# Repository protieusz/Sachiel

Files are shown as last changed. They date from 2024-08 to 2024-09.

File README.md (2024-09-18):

# Sachiel
Sachiel, inspired by Grumpy, 34 keys custom keyboard with 25mm trackball

# Description
Sachiel is a 34 keys custom keyboard with an integrated 25mm trackball.
Even though Sachiel is inspired by Grumpy but the KLE layout is done from scratch with added missing keys. Nothing from the Grumpy's design was taken for modding i.e the pcb files or the stl. 
Sachiel name was derived from one of the angels of an anime.

The missing keys of Q, P, B and N were added to make it a standard 30 alpha keys. The win key and the enter key were add to row 3 and 10 of the layout.
The 2 keys, backspace and space were shrink to 1U.

The keeb is power by RP2040 Core-A mcu which you can get from AE. The rest of the components are purchased from LCSC.

The components are pcba by me using a hot plate and some hand soldering for the mcu, ESD, fuse, USB C and the switches. During designing, due to spacing issue for the ESD and the fuse, I got them to appear to the top side of pcb.

PMW3360 sensor is used for the trackball as per usual.

As for the case design, I have tried printing in both PLA and matte resin. The PLA has a good switch friction fit and working integrated trackball holder but the resin had loose switch holes and super super tight fitting M2 inserts. So print resin at your own risk I didn't use resin for this build.

As for the trackball ball, you can refer to my previous different designs for reference. Overall POM ball works the best for me. Other balls are hit and miss. Build this keeb on your own risk.

QMK code is the same modified from aki27's bally code. I don't how the code works and I just integrated my matrix and some trial and errors and it works now.

# Full Production




41BBA1AD-F132-4E0E-9B04-4C7E31181316














# Renders

Screenshot 2024-07-20 at 11 03 13 PM
Screenshot 2024-07-20 at 11 03 25 PM
Screenshot 2024-07-20 at 9 27 32 PM
Screenshot 2024-07-20 at 9 27 11 PM
Screenshot 2024-07-20 at 7 22 08 PM
Screenshot 2024-07-20 at 7 20 41 PM
Screenshot 2024-07-20 at 7 20 30 PM

# License

</a></p>

You are free to:

Share — copy and redistribute the material in any medium or format

Adapt — remix, transform, and build upon the material

The licensor cannot revoke these freedoms as long as you follow the license terms.
Under the following terms:

Attribution — You must give appropriate credit, provide a link to the license, and indicate if changes were made. You may do so in any reasonable manner, but not in any way that suggests the licensor endorses you or your use.

NonCommercial — You may not use the material for commercial purposes.

ShareAlike — If you remix, transform, or build upon the material, you must distribute your contributions under the same license as the original.

No additional restrictions — You may not apply legal terms or technological measures that legally restrict others from doing anything the license permits.

Sachiel by ProtieusKeebs is licensed under [CC BY-NC-SA 4.0](https://creativecommons.org/licenses/by-nc-sa/4.0/?ref=chooser-v1)

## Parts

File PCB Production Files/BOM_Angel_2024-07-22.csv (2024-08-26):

ID | Name | Designator | Footprint | Quantity | Manufacturer Part | Manufacturer | Supplier | Supplier Part | Price | link
1 | SM4007PL | D000,D001,D002,D003,D004,D005,D006,D007,D008,D009,D100,D101,D102,D103,D104,D105,D106,D107,D108,D109,D200,D201,D202,D203,D204,D205,D206,D207,D208,D209,D302,D304,D305,D307 | SOD-123F_L2.8-W1.8-LS3.7-RD | 34 | SM4007PL | MDD | LCSC | C64898 | 0.007 | https://item.szlcsc.com/60254.html
2 | 4.7uF | C17,C19,C20 | C0402 | 3 | CL05A475MP5NRNC | SAMSUNG(三星) | LCSC | C23733 | 0.005 | https://lcsc.com/eda_search?q=C23733&%26type=1&ref=editor
3 | 100nF | C18 | C0402 | 1 | CL05B104KB54PNC | SAMSUNG(三星) | LCSC | C307331 | 0.005 | https://lcsc.com/eda_search?q=C307331&%26type=1&ref=editor
4 | 5.1kΩ | R1,R2 | R0402 | 2 | 0402WGF5101TCE | UNI-ROYAL(厚声) | LCSC | C25905 | 0.001 | https://item.szlcsc.com/323315.html
5 | 10kΩ | R10,R12,R13 | R0402 | 3 | 0402WGF1002TCE | UNI-ROYAL(厚声) | LCSC | C25744 | 0.001 | https://lcsc.com/eda_search?q=C25744&%26type=1&ref=editor
6 | 39Ω | R11 | R0402 | 1 | 0402WGJ0390TCE | UNI-ROYAL(厚声) | LCSC | C25164 |  | https://lcsc.com/eda_search?q=C25164&%26type=1&ref=editor
7 | 15kΩ | R14 | R0402 | 1 | 0402WGF1502TCE | UNI-ROYAL(厚声) | LCSC | C25756 | 0.001 | https://lcsc.com/eda_search?q=C25756&%26type=1&ref=editor
8 | RP2040-Core-A | U1 | RP2040-CORE-A | 1
9 | AP2127K-ADJTRG1 | U10 | SOT-23-5_L3.0-W1.7-P0.95-LS2.8-BR | 1 | AP2127K-ADJTRG1 | DIODES(美台) | LCSC | C96343 | 0.072 | https://lcsc.com/eda_search?q=C96343&%26type=1&ref=editor
10 | PMW3360DM-T2QU | U11 | PMW3360DM-T2QU.PACK | 1 | PMW3360DM-T2QU |  |  |  |  | http://www.pixart.com/upload/PMS0058-PMW3360DM-T2QU-NNDS-R1.30-06042016_20160902201411.pdf
11 | TYPE-C-31-M-12 | USBC1 | USB-C_SMD-TYPE-C-31-M-12 | 1 | TYPE-C-31-M-12 | 韩国韩荣 | LCSC | C165948 | 0.157 | https://so.szlcsc.com/global.html?c=&k=C165948
12 | Switch | K000,K001,K002,K003,K004,K005,K006,K007,K008,K009,K100,K101,K102,K103,K104,K105,K106,K107,K108,K109,K200,K201,K202,K203,K204,K205,K206,K207,K208,K209,K302,K304,K305,K307 | CHERRY_MX_100_MILLMAX | 34
13 | PRTR5V0U2X,215 | D11 | SOT-143_L2.9-W1.3-P1.92-LS2.3-BR | 1 | PRTR5V0U2X,215 | Nexperia(安世) | LCSC | C12333 | 0.089 | https://item.szlcsc.com/280548.html
14 | BSMD0805-020-15V | F1 | F0805 | 1 | BSMD0805-020-15V | BHFUSE(佰宏) | LCSC | C883103 | 0.043 | https://item.szlcsc.com/343298.html

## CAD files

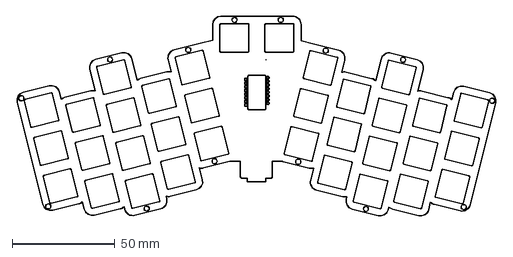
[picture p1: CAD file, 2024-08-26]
Angel Final PCB.dxf
233.6 x 97.5 mm

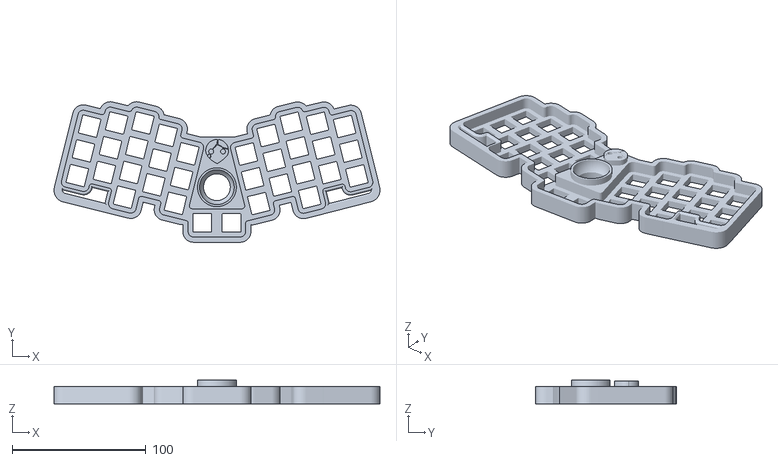
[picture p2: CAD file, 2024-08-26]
Sachiel STLs/SachielTop.stl
243.7 x 105.1 x 17.8

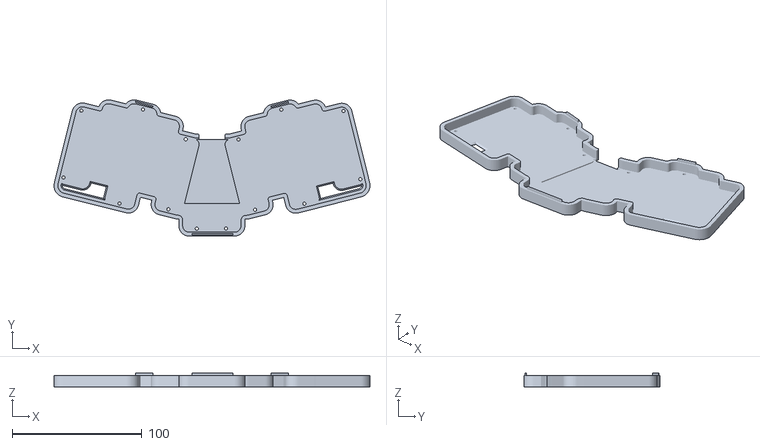
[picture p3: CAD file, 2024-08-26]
Sachiel STLs/Sachiel Bottom.stl
243.7 x 105.1 x 10.6

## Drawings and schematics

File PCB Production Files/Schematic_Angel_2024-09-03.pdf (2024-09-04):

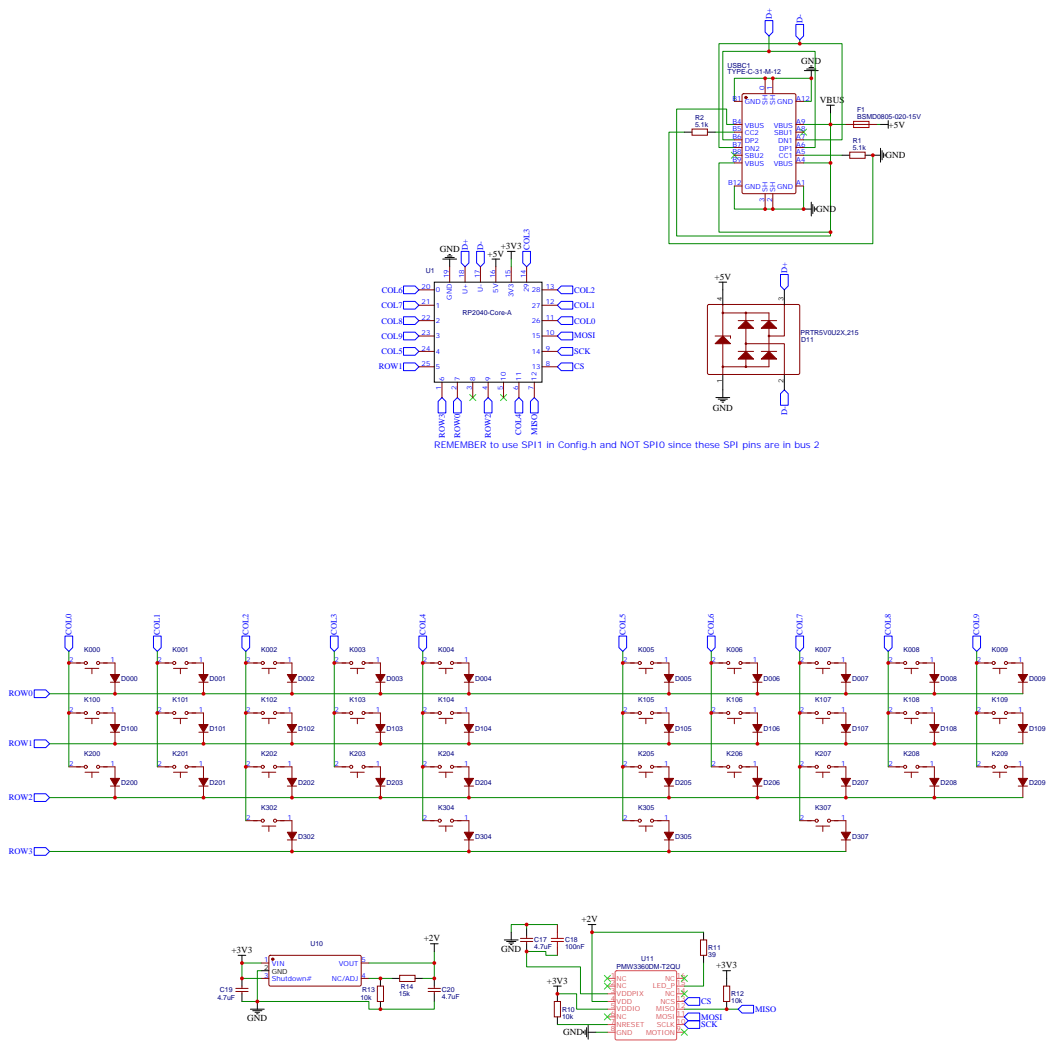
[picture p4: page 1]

REMEMBER to use SPI1 in Config.h and NOT SPI0 since these SPI pins are in bus 2 ROW³

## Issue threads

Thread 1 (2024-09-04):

Nice work! I am also interested in designing KB with trackball, so I have some questions if you could find time to answer.

klesh, 2024-09-04:
1. I didn't see any bearing to reduce the traction. How does it feel when rolling the ball? Is it smooth enough?
2. Are there any cheaper sensors as replacements for PMW3360?

protieusz, 2024-09-04:
1. Unfortunately I haven't learned how to design those cutouts for rollers. I have tried rollers in other designs and they feel slightly smoother. Without rollers it is useable and not super super smooth. Also depends on the case material PLA is good enough for me. Nylon and resin you will need POM balls. It depends on tolerance of your printer. Sometimes I get really good compatibility with all types of balls but most of the time POM ball always works.
2. As for pmw sensor sorry there are not cheaper version since pmw is proprietary and the best in the market. There is the 3610 that most ppl use for wireless built but I dunno anything about it other than the name. You will have to research on your own. I am content with wired custom keebs. Good luck.

klesh, 2024-09-04:
@protieusz Lovely, thanks for the information, it is very helpful.

Closed 2024-09-04.

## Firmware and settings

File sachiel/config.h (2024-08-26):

// Copyright 2024 ProtieusKeebs
// SPDX-License-Identifier: GPL-2.0-or-later

#pragma once

//#define VIAL_KEYBOARD_UID {0xC4, 0x18, 0xCC, 0x6D, 0x1C, 0x16, 0x5B, 0x8D}
//#define VIAL_UNLOCK_COMBO_ROWS {0, 0}
//#define VIAL_UNLOCK_COMBO_COLS {1, 11}

/* VIA */
//#define DYNAMIC_KEYMAP_LAYER_COUNT 8


/* key matrix size */
//#define MATRIX_COLS 13
//#define MATRIX_ROWS 4


/* tapping term */
// #define TAPPING_FORCE_HOLD
//#define TAPPING_TERM 200
// #define IGNORE_MOD_TAP_INTERRUPT

#define RP2040_BOOTLOADER_DOUBLE_TAP_RESET // Activates the double-tap behavior
#define RP2040_BOOTLOADER_DOUBLE_TAP_RESET_TIMEOUT 200U // Timeout window in ms in which the double tap can occur.

#ifdef COMBO_ENABLE
#    define COMBO_COUNT 4
#    define COMBO_TERM 200
#endif

/* Encoder */
//#define ENCODERS_PAD_A { GP11 }
//#define ENCODERS_PAD_B { GP12 }
//#define ENCODER_RESOLUTION 4

/* Matrix*/
//#define MATRIX_COL_PINS { GP25, GP24, GP23, GP22, GP21, GP26, GP27, GP20, GP19, GP18, GP17, GP16, GP13 }
//#define MATRIX_ROW_PINS { GP28, GP10, GP14, GP15 }

/* COL2ROW, ROW2COL */
//#define DIODE_DIRECTION COL2ROW


/* Set 0 if debouncing isn't needed */
//#define DEBOUNCE 5


/* Mechanical locking support. Use KC_LCAP, KC_LNUM or KC_LSCR instead in keymap (Very Important for Scroll Lock!!!) */
#undef LOCKING_SUPPORT_ENABLE
/* Locking resynchronize hack */
#undef LOCKING_RESYNC_ENABLE


/* Trackball */

#ifdef POINTING_DEVICE_ENABLE

//#    undef RP_SPI_USE_SPI0
//#    define RP_SPI_USE_SPI0 TRUE
//#    undef RP_SPI_USE_SPI1
//#    define RP_SPI_USE_SPI1 FALSE
#    define SPI_DRIVER SPID1

//#    define SPI_SCK_PIN GP22 //6
//#    define SPI_MISO_PIN GP24 //4
//#    define SPI_MOSI_PIN GP23 //7
#    define SPI_SCK_PIN GP14
#    define SPI_MISO_PIN GP12
#    define SPI_MOSI_PIN GP15

#endif


#ifndef PMW33XX_CS_PIN
#    define PMW33XX_CS_PIN GP13
#endif
#define POINTING_DEVICE_INVERT_X
#define POINTING_DEVICE_INVERT_Y
//#define ROTATIONAL_TRANSFORM_ANGLE 90
#define POINTING_DEVICE_ROTATION_180

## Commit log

2024-08-26 Production files
    [BOM_Angel_2024-07-22.csv, PickAndPlace_PCB_Angel_2024-07-22.csv]
2024-08-26 Case files
    [Sachiel Bottom.stl, SachielTop.stl]

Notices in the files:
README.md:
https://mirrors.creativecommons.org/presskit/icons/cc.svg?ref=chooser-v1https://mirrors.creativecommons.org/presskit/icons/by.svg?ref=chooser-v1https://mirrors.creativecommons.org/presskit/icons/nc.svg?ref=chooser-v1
